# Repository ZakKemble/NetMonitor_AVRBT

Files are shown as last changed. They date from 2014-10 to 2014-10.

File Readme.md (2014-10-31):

Bluetooth Net Monitor
=====================

http://blog.zakkemble.co.uk/bluetooth-net-monitor-v2/

The firmware .hex files (bootloader & monitor) are compiled for ATmega328P

Fuses for ATmega328/328P  
External full swing crystal 16K CK/14CK + 65ms startup  
Serial program (SPI) enabled  
Brown-out at 2.7V  
Bootloader enabled, 2048 words  
High:		0xD8 (or 0xDF for no bootloader)  
Low:		0xF7  
Extended:	0xFD

--------

`./modem/adsl_btnetmon`  
This is the CGI script which runs on the modem to get ADSL stats (Only tested on Netgear DG834G v3 running OpenWRT)

`./router/btnetmon`  
This is the main program which runs on the router, the binary was compiled on Debain 7.7 x64 so it may or may not work without having to recompile (differently named libs, etc). More info in `./router/Readme.md`

`./utils/lcdBitmapConverter.exe`  
Utility to convert red channel of images (in `./imgs/`) to pixel intensity byte array

`./driver/` contains parts of libusb-win32 available at http://sourceforge.net/apps/trac/libusb-win32/wiki  
`./firmware/` contains the V-USB library available at http://www.obdev.at/products/vusb/index.html  
`./firmware/USBaspLoader/` contains the USBaspLoader bootloader available at https://github.com/baerwolf/USBaspLoader  
Font used is MicroExtendFLF (bold italics) available at http://www.fontspace.com/casady-and-greene/microextendflf  
Third party contents are copyrighted by their respective authors.  
My productions are published under GNU GPL v3 (see License.txt).

--------

Zak Kemble

contact@zakkemble.co.uk

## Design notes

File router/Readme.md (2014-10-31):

Quick setup guide for the router
================================

Plug a USB bluetooth adapter into the router  
Plug the net monitor into anywhere

Compiling:
```
apt-get install gcc liboping-dev libcurl4-gnutls-dev libbluetooth-dev bluez
chmod +x make.sh
./make.sh
```

Search for the net monitor:
```
hcitool scan
```

One of the lines should be the net monitor, copy the hex address string for it.

Set up config:  
Open ./btnetmon.conf  
Set btaddr to the hex address for the net monitor  
`btaddr=AA:BB:CC.....`  
Make sure all the other settings are OK  

Paring:  
`bluetooth-agent 1234 &`  
1234 is the PIN for the net monitor.  

Run main program:  
`./btnetmon -d`

If it successfully connects then CTRL + C.

`pkill bluetooth-agent`  
You don't need to do the bluetooth-agent things again, it's only needed for the first connection.

`./btnetmon`  
Program should now be running in the background.

If for some crazy reason it stops being able to connect to the net monitor run:  
`rm -r /var/lib/bluetooth/(btaddr)/`  
That will clear all saved settings for the bluetooth device with that address, then do the bluetooth-agent stuff again.

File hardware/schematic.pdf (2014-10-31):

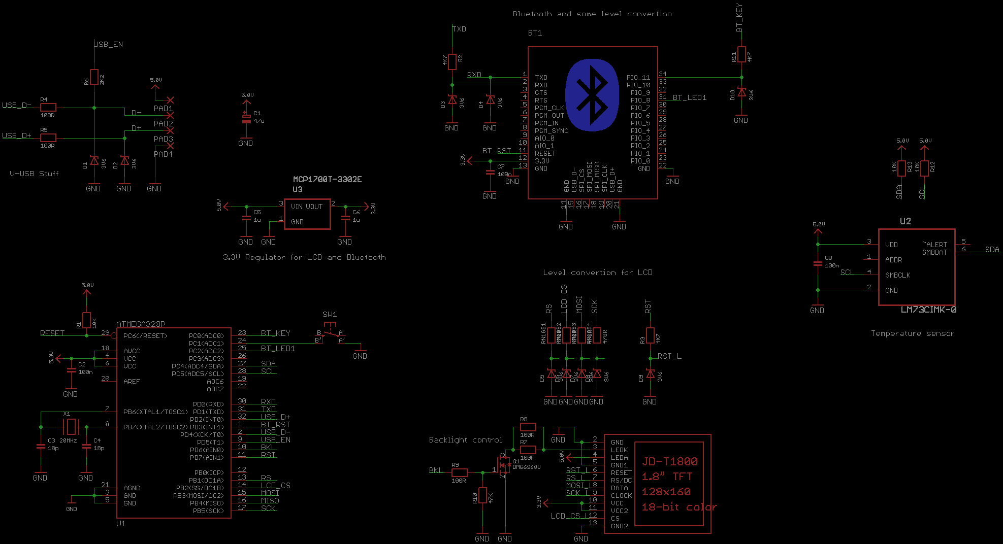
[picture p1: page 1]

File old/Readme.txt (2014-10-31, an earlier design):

THIS IS OLD STUFF FOR BLUETOOTH NET MONITOR V1

Bluetooth Net Monitor
http://blog.zakkemble.co.uk/bluetooth-net-monitor/

The .hex file in ./firmware/hex/ is compiled for ATmega328P
Fuse settings are in ./firmware/src/config.h

./scripts/modem/adsl_btnetmon
This is the CGI script which runs on the modem to get ADSL stats

./scripts/router/btnetmon.sh
This is the main shell script which runs on the router

./utils/lcdBitmapConverter.exe
Utility to convert red channel of images (in ./imgs/) to pixel intensity byte array

The ./driver/ directory contain parts of libusb-win32 available at http://sourceforge.net/apps/trac/libusb-win32/wiki
The ./firmware/src/ directory and subdirectories contains the V-USB library available at http://www.obdev.at/products/vusb/index.html
Third party contents are copyrighted by their respective authors.
My productions are published under GNU GPL v3 (see License.txt).

--------

Zak Kemble
me@zakkemble.co.uk

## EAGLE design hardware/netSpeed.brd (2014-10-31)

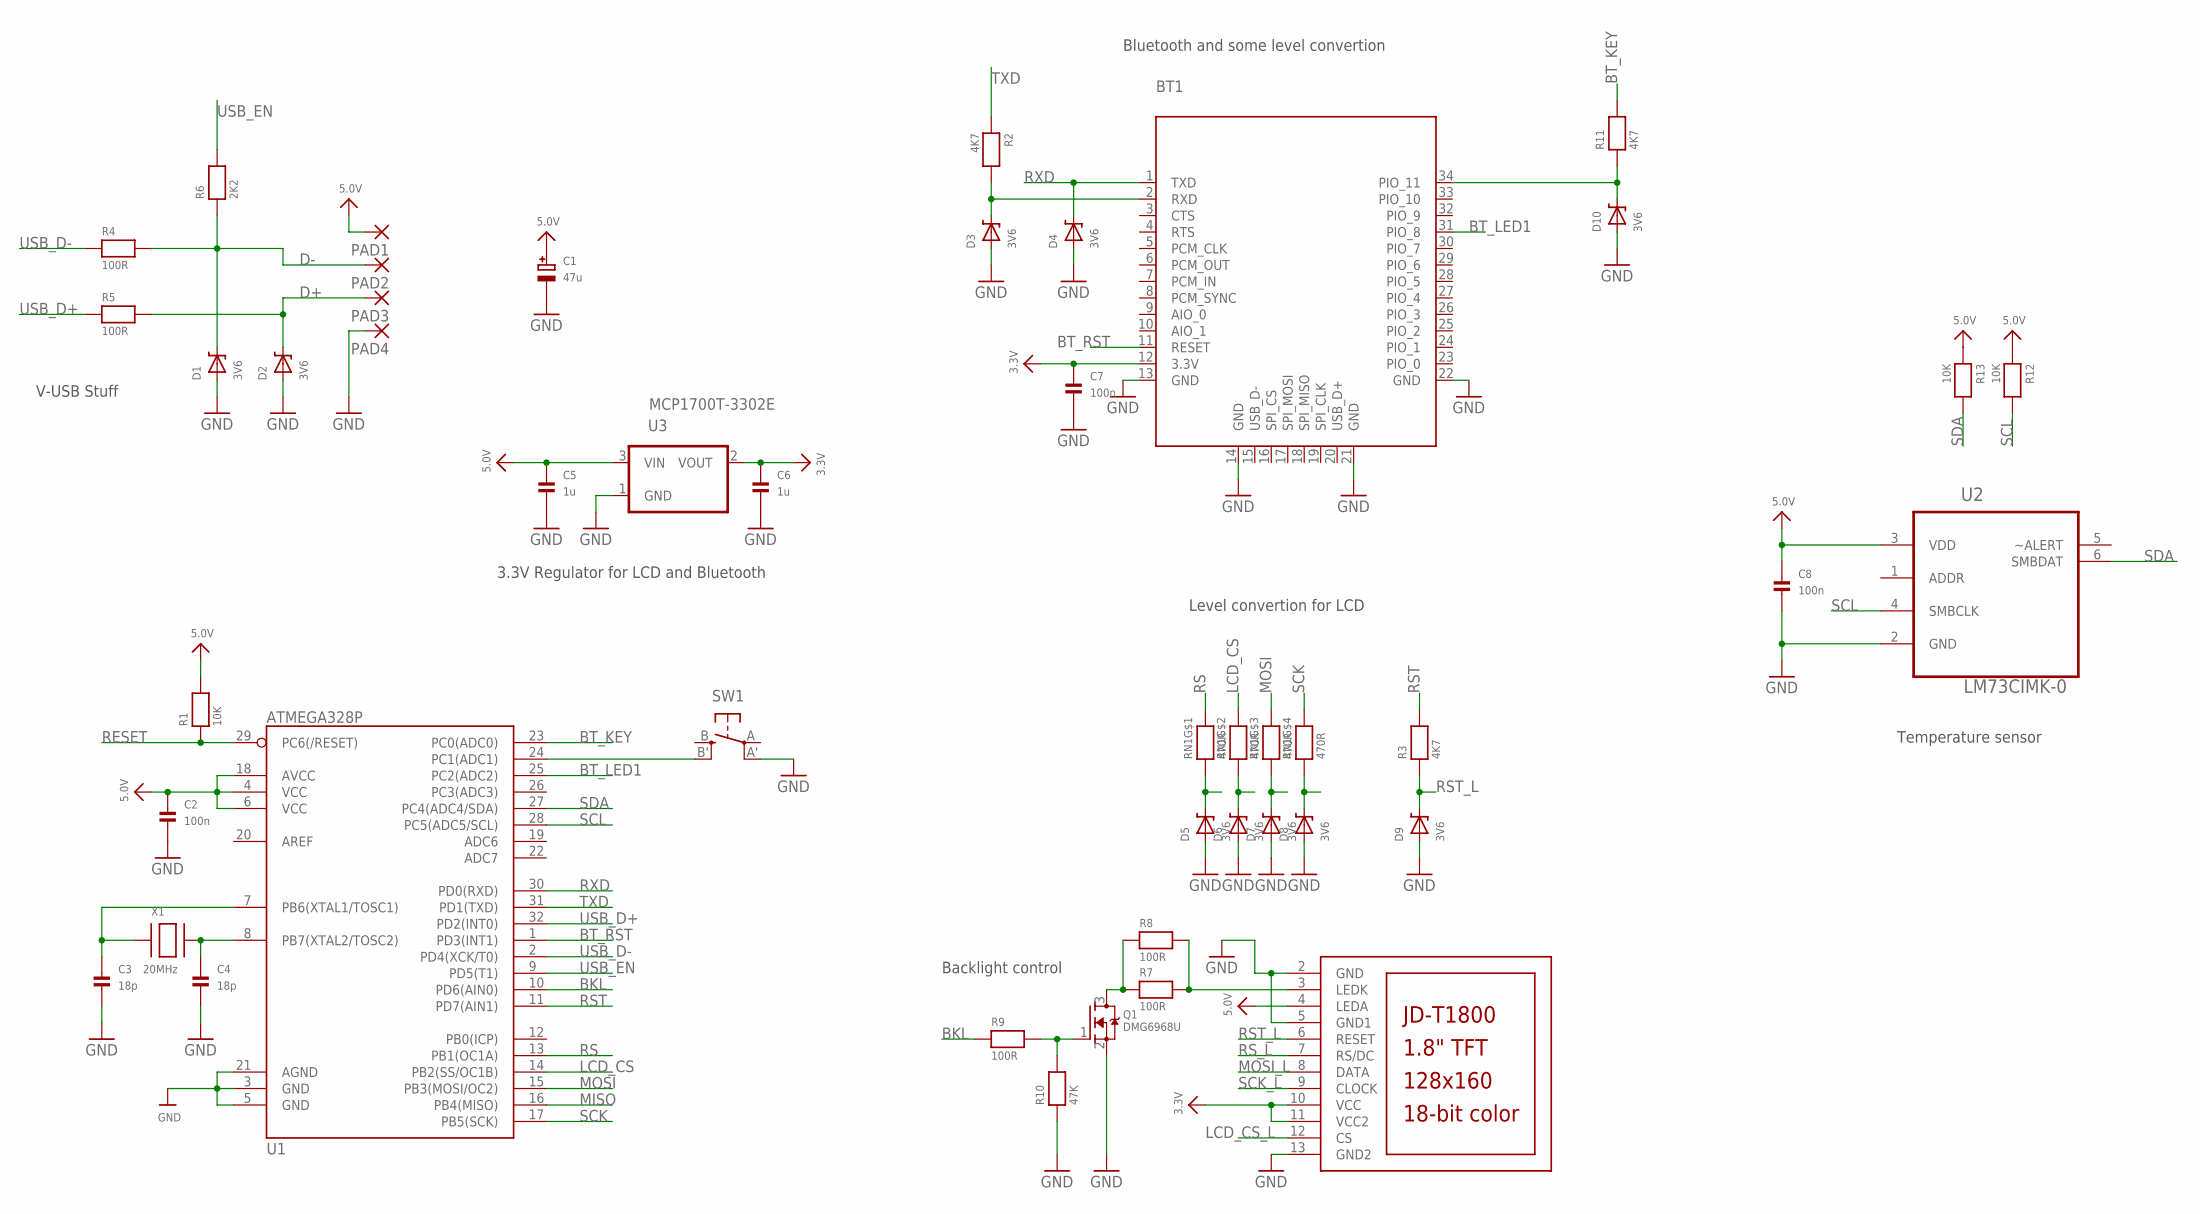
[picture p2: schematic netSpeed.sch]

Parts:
BT1: BLUETOOTH_MODULE
C1: 47u; PANASONIC_C
C2, C7, C8: 100n; 0805
C3, C4: 18p; 0805
C5, C6: 1u; 0805
D1, D2, D3, D4, D5, D6, D7, D8, D9, D10: 3V6; SOD-323
LCD1: JD-T1800
PAD1, PAD2, PAD3, PAD4: SMD2; SMD1,27-2,54
Q1: DMG6968U; SOT23-WIDE
R1, R12, R13: 10K; 0805
R2, R3, R11: 4K7; 0805
R4, R5, R7, R8, R9: 100R; 0805
R6: 2K2; 0805
R10: 47K; 0805
RN1: 470R; RESPACK_4X0603
SW1: SPST_TACT; TACT_SMD
U1: ATMEGA328P; TQFP32-08
U2: LM73CIMK-0; SOT95P285X100-6N
U3: MCP1700T-3302E; SOT-23
X1: 20MHz; NX5032

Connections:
3.3V: BT1.12 (3.3V), C6.1, C7.1, LCD1.10 (VCC), LCD1.11 (VCC2), U3.2 (VOUT)
5.0V: C1.+, C2.1, C5.1, C8.1, LCD1.4 (LEDA), PAD1.1, R1.2, R12.1, R13.1, U1.4 (VCC), U1.6 (VCC), U1.18 (AVCC), U2.3 (VDD), U3.3 (VIN)
BKL: R9.1, U1.10 (PD6(AIN0))
BT_KEY: R11.2, U1.23 (PC0(ADC0))
BT_KEY_L: BT1.34 (PIO_11), D10.C, R11.1
BT_LED1: BT1.31 (PIO_8), U1.25 (PC2(ADC2))
BT_RST: BT1.11 (RESET), U1.1 (PD3(INT1))
D+: D2.C, PAD3.1, R5.2
D-: D1.C, PAD2.1, R4.2, R6.1
GND: BT1.13 (GND), BT1.14 (GND), BT1.21 (GND), BT1.22 (GND), C1.-, C2.2, C3.2, C4.2, C5.2, C6.2, C7.2, C8.2, D1.A, D2.A, D3.A, D4.A, D5.A, D6.A, D7.A, D8.A, D9.A, D10.A, LCD1.2 (GND), LCD1.5 (GND1), LCD1.13 (GND2), PAD4.1, Q1.2 (S), R10.1, SW1.A' (P1), U1.3 (GND), U1.5 (GND), U1.21 (AGND), U2.2 (GND), U3.1 (GND)
LCD_CS: RN1.7 (2), U1.14 (PB2(SS/OC1B))
LCD_CS_L: D6.C, LCD1.12 (CS), RN1.2 (1)
MISO: U1.16 (PB4(MISO))
MOSI: RN1.6 (2), U1.15 (PB3(MOSI/OC2))
MOSI_L: D7.C, LCD1.8 (DATA), RN1.3 (1)
unnamed: SW1.B' (S1), U1.24 (PC1(ADC1))
unnamed: C3.1, U1.7 (PB6(XTAL1/TOSC1)), X1.P$1
unnamed: C4.1, U1.8 (PB7(XTAL2/TOSC2)), X1.P$2
unnamed: Q1.1 (G), R9.2, R10.2
unnamed: Q1.3 (D), R7.1, R8.1
unnamed: LCD1.3 (LEDK), R7.2, R8.2
RESET: R1.1, U1.29 (PC6(/RESET))
RS: RN1.8 (2), U1.13 (PB1(OC1A))
RST: R3.2, U1.11 (PD7(AIN1))
RST_L: D9.C, LCD1.6 (RESET), R3.1
RS_L: D5.C, LCD1.7 (RS/DC), RN1.1
RXD: BT1.1 (TXD), D4.C, U1.30 (PD0(RXD))
SCK: RN1.5 (2), U1.17 (PB5(SCK))
SCK_L: D8.C, LCD1.9 (CLOCK), RN1.4 (1)
SCL: R12.2, U1.28 (PC5(ADC5/SCL)), U2.4 (SMBCLK)
SDA: R13.2, U1.27 (PC4(ADC4/SDA)), U2.6 (SMBDAT)
TXD: R2.1, U1.31 (PD1(TXD))
TXD_L: BT1.2 (RXD), D3.C, R2.2
USB_D+: R5.1, U1.32 (PD2(INT0))
USB_D-: R4.1, U1.2 (PD4(XCK/T0))
USB_EN: R6.2, U1.9 (PD5(T1))

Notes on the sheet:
Level convertion for LCD
Temperature sensor
Bluetooth and some level convertion
V-USB Stuff
3.3V Regulator for LCD and Bluetooth
Backlight control

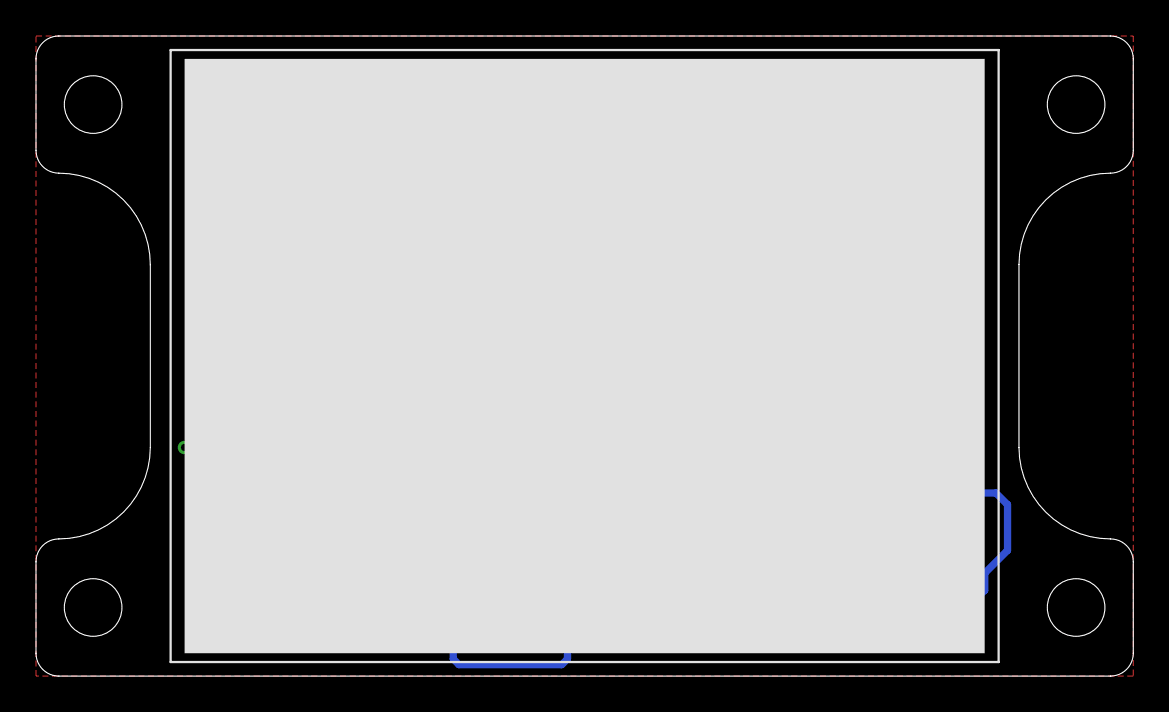
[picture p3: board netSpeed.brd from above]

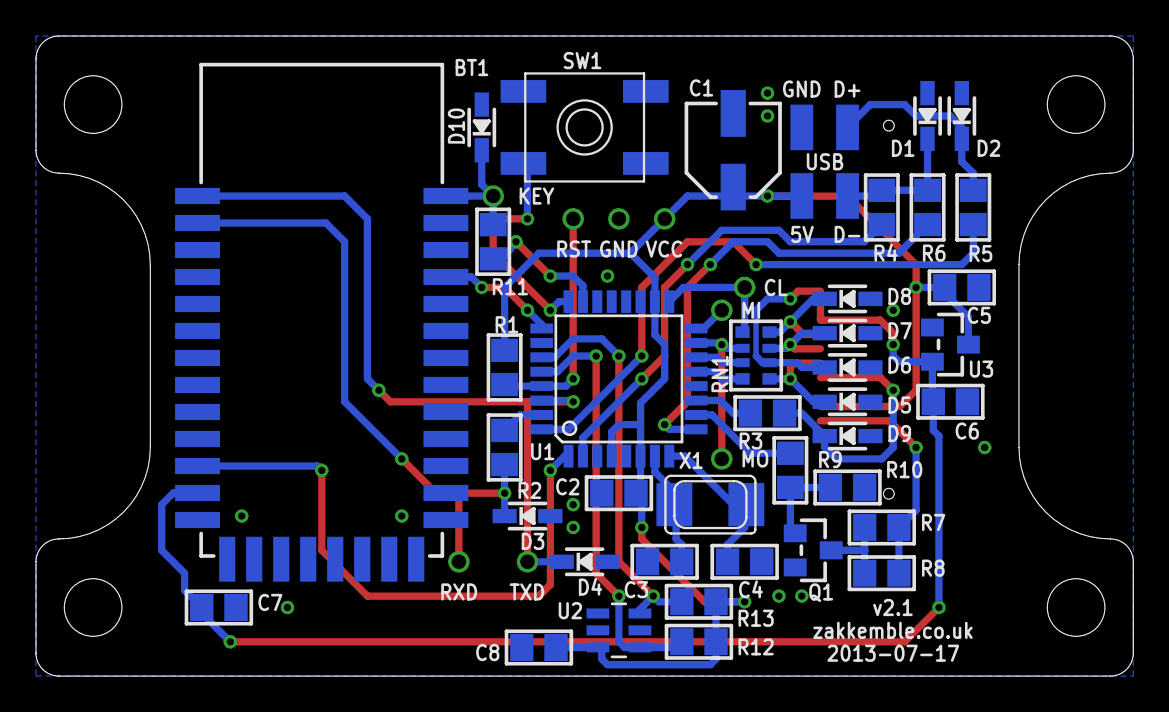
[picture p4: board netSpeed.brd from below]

Board: 2 copper layers, 61.0 x 35.6 mm, 44 parts (43 on the bottom side), 35 nets.

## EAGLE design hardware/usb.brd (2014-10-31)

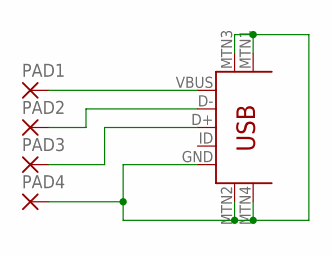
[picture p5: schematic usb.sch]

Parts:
PAD1, PAD2, PAD3, PAD4: SMD2; SMD1,27-2,54
USB1: USB-MINIB-5PIN; USB-MINIB

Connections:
GND: PAD4.1, USB1.GND, USB1.MTN1 (MTN2), USB1.MTN2 (MTN3), USB1.MTN3 (MTN1), USB1.MTN4
unnamed: PAD1.1, USB1.VBUS
unnamed: PAD2.1, USB1.D-
unnamed: PAD3.1, USB1.D+

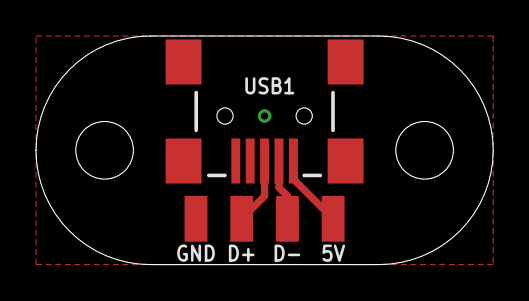
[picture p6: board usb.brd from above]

Board: 2 copper layers, 25.4 x 12.7 mm, 5 parts (0 on the bottom side), 4 nets.

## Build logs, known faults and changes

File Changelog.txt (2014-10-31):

2014-10-31:
	Router program:
	- Support for USB bluetooth adapters (rfcomm)
	- Support for non-point-to-point interfaces
	- Can manually set sync rates

	Net Monitor:
	- Now shows speeds in MBps with 1 decimal place (0.0 - 99.9MBps)

2013-08-17:
	- Version 2!
	- New PCB design
	- Revamped micorcontroller code, reduced RAM usage, improved performance
	- New router program, now written in C, much more efficient than the old shell script
	- New host program, written in C# .NET and uses LibUsbDotNet. Still in early development, but allows image uploading, drawing and controlling display brightness
	- Added a bootloader (USBaspLoader) for easy firmware updating over USB

2013-01-09:
	- Initial release

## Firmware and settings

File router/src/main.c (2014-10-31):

/*
 * Project: Bluetooth Net Monitor
 * Author: Zak Kemble, contact@zakkemble.co.uk
 * Copyright: (C) 2013 by Zak Kemble
 * License: GNU GPL v3 (see License.txt)
 * Web: http://blog.zakkemble.co.uk/bluetooth-net-monitor-v2/
 */

// TODO:
// Keep byte count files always open?
// Instead of ping and main threads having their own sleep(), have a single sleep() which notifies other threads?
// If no responce from modem then sync speeds should be set to 0
// PIN and BT adpater settings
// Support routers that need to go through multiple login pages and cookies and stuff
// http://icanhazip.com/

// BUGS:
// Sometimes program crashes when interface comes up
// Single instance stuff doesn't work yet
// Ping doesn't work if non-root, needs CAP_NET_RAW capability since liboping uses raw sockets
// If interface is unavailable ping is 999 (good), but lost packet count does not go up (bad)


// v1.1 changes
// Fixed cURL stuff stops working with 'Failure when receiving data from the peer'
// Support for BT USB adapters
// Renamed adsl.c to modem.c
// Can now manually set sync rate
// Support for speeds over 999 KBps / syncs over 9999 Kbps (now goes to 99.9MBps / 99999 Kbps)
// Support non-Point-to-Point interfaces



#include "common.h"

#define SENDBUFFER_SIZE	30

typedef struct{
	byte data[SENDBUFFER_SIZE];
	byte* ptr;
}s_sendBuffer;

static void incArgIdx(int*, int);
static bool alreadyRunning(void);
static void update(void);
static void bufferWriter(s_sendBuffer*, void*, byte);
static ulong readFileAsNum(const char*);
//static int writeToBuffer(char**, const char*, ...);
static void print_ip(uint32_t);

static bool daemonize;

// Byte count file locations
static char* byteCountFileRx;
static char* byteCountFileTx;

typedef void (*adapterInit_f)(void);
typedef void (*adapterEnd_f)(void);
typedef void (*adapterSend_f)(void*, size_t);

static adapterInit_f adapterInitFunc;
static adapterEnd_f adapterEndFunc;
static adapterSend_f adapterSendFunc;

int main(int argc, char **argv)
{
	puts("Bluetooth Net Monitor v1.1");
	puts("zakkemble.co.uk");

//	syslog(LOG_DAEMON | LOG_INFO, "Bluetooth Net Monitor v1.0 started");

	daemonize = true;
	char* configFile = NULL;

	// Check args
	for(int argIdx = 1;argIdx<argc;argIdx++)
	{
		if(strcmp(argv[argIdx], "-h") == 0 || strcmp(argv[argIdx], "--help") == 0)
		{
			printf("Usage: %s [--help|-h] [-c <file>] [-d]", argv[0]);
			puts("");
			puts(" --help|-h : Help (This)");
			puts(" -c <file> : Config file location (Default looks for btnetmon.conf in working directory)");
			puts("        -d : Don't daemonize (Debugging)");
			exit(EXIT_SUCCESS);
		}
		else if(strcmp(argv[argIdx], "-c") == 0)
		{
			incArgIdx(&argIdx, argc);
			asprintf(&configFile, "%s", argv[argIdx]);
		}
		else if(strcmp(argv[argIdx], "-d") == 0)
			daemonize = false;
	}

	// Default config file
	if(!configFile)
		asprintf(&configFile, "btnetmon.conf");

	// Load config
	config_init(configFile);

	// No longer needed
	free(configFile);

	// Make sure only 1 instance is running
	if(alreadyRunning())
	{
		fputs("Error: Another instance is already running", stderr);
		exit(EXIT_FAILURE);
	}

	// Run in background
	if(daemonize && daemon(0, 0) < 0)
		error(EXIT_FAILURE, errno, "Failed to daemonize");

	// Bluetooth adapter type
	char* btType = NULL;
	config_val("bttype", &btType);
	
	if(strcmp(btType, "serial") == 0)
	{
		adapterInitFunc = serial_init;
		adapterEndFunc = serial_end;
		adapterSendFunc = serial_send;
	}
	else if(strcmp(btType, "usb") == 0)
	{
		adapterInitFunc = rfcomm_init;
		adapterEndFunc = rfcomm_end;
		adapterSendFunc = rfcomm_send;
	}
	else
	{
		fprintf(stderr, "Error: Unknown btType option: %s\n", btType);
		exit(EXIT_FAILURE);
	}

	free(btType);

	// Init
	curl_global_init(CURL_GLOBAL_ALL);
	adapterInitFunc();
	email_init();
	modem_init();
	iface_init();
	ping_init();

	// Get interface byte count file locations
	char* interface = NULL;
	config_val("interface", &interface);

	asprintf(&byteCountFileRx, "/sys/class/net/%s/statistics/rx_bytes", interface);
	asprintf(&byteCountFileTx, "/sys/class/net/%s/statistics/tx_bytes", interface);

	free(interface);

	// Free config resources
	config_end();

	struct timespec sleepTime;
	sleepTime.tv_sec = 1;
	sleepTime.tv_nsec = 0;

	//for(int i=0;i<5;i++)
	while(1)
	{
		nanosleep(&sleepTime, NULL);

		//struct timespec startTime;
		//clock_gettime(CLOCK_THREAD_CPUTIME_ID, &startTime);

		update();

		//struct timespec endTime;
		//clock_gettime(CLOCK_THREAD_CPUTIME_ID, &endTime);

		//printf("Total time: %ldns\n", endTime.tv_nsec - startTime.tv_nsec);
	}

	// Free everything, although program never ends unless its manually killed
	free(byteCountFileRx);
	free(byteCountFileTx);
	adapterEndFunc();
	iface_end();
	email_end();
	modem_end();
	ping_end();
	curl_global_cleanup();

	return EXIT_SUCCESS;
}

static void incArgIdx(int* argIdx, int argc)
{
	if(++*argIdx >= argc)
	{
		puts("Error: Bad/missing arguments");
		exit(EXIT_FAILURE);
	}
}

// This isn't working quite right yet, file lock stuff doesn't lock...
static bool alreadyRunning()
{
	char* pid = NULL;
	config_val("pid", &pid);

	// If PID file setting is empty then don't do any PID stuff
	if(strlen(pid) < 1)
		return false;

	// Create/open file
	int pid_file = open(pid, O_CREAT | O_WRONLY | O_TRUNC, 0644);

	if(pid_file < 0)
	{
		perror("Unable to create PID file");
		exit(EXIT_FAILURE);
	}

	if(pid)
		free(pid);

	// Get PID
	char* buff = NULL;
	int len = asprintf(&buff, "%d", getpid());

	// Write PID
	int res = write(pid_file, buff, len);
	UNUSED(res);

	if(buff)
		free(buff);

	// Try to lock file
	struct flock lock;
	lock.l_type		= F_WRLCK;
	lock.l_whence	= SEEK_SET;
	lock.l_start	= 0;
	lock.l_len		= 0;
	lock.l_pid		= getpid();
	int rc = fcntl(pid_file, F_SETLK, &lock);

	return (rc != 0);
}

// Main update function
static void update()
{
	static ulong lastBytesDown;
	static ulong lastBytesUp;

	// Start update threads and stuff
	email_update();
	modem_update();
	iface_update();

	// Get what IP to ping
	ping_setHost(iface_gateway());

	// Get current byte count
	ulong bytesDown = readFileAsNum(byteCountFileRx);
	ulong bytesUp = readFileAsNum(byteCountFileTx);

	// Work out rates
	s_netUpDown rate;
	rate.down = (uint32_t)((bytesDown - lastBytesDown) / 1024);
	rate.up = (uint32_t)((bytesUp - lastBytesUp) / 1024);

	// Save byte counts for next time
	lastBytesDown = bytesDown;
	lastBytesUp = bytesUp;

	// IP
	uint32_t ip = iface_ip();

	// Time
	time_t rawTime;
	struct tm* timeInfo;
	time(&rawTime);
	timeInfo = localtime(&rawTime);

	// ADSL sync rates
	s_netUpDown adsl = modem_get();

	// Email
	bool hasEmail = email_get();

	// Ping
	uint16_t ping = ping_get();

	// Ping loss
	byte loss = ping_loss();

	if(!daemonize)
	{
		// Show info
		printf("Sync ---- Down: %u -- Up: %u\n", adsl.down, adsl.up);
		printf("Rates ---- Down: %u -- Up: %u\n", rate.down, rate.up);
		print_ip(ip);
		printf("Gateway: %s\n", iface_gateway());
		printf("Ping: %hu | Loss: %hhu\n", ping, loss);
		hasEmail ? puts("Email!") : puts("No email");
		printf("Time: %s\n", asctime(timeInfo));
	}

	// Write data to buffer for sending to the net monitor
	s_sendBuffer buffer;
	memset(&buffer.data, 0, sizeof(buffer.data));
	buffer.ptr = buffer.data;

	bufferWriter(&buffer, &adsl.down, 4);
	bufferWriter(&buffer, &adsl.up, 4);
	bufferWriter(&buffer, &rate.down, 4);
	bufferWriter(&buffer, &rate.up, 4);
	bufferWriter(&buffer, &ping, 2);
	bufferWriter(&buffer, &loss, 1);
	bufferWriter(&buffer, &ip, 4);
	bufferWriter(&buffer, &hasEmail, 1);
	bufferWriter(&buffer, &timeInfo->tm_hour, 1);
	bufferWriter(&buffer, &timeInfo->tm_min, 1);
	bufferWriter(&buffer, &timeInfo->tm_sec, 1);
	bufferWriter(&buffer, &timeInfo->tm_mday, 1);
	bufferWriter(&buffer, &timeInfo->tm_mon, 1);
	bufferWriter(&buffer, &timeInfo->tm_year, 1);

	if(!daemonize)
	{
		// Show contents
		for(size_t i=0;i<sizeof(buffer.data);i++)
			printf("%02x ", buffer.data[i]);
		puts("");

		puts("----");
	}

	// Send to the net monitor
	adapterSendFunc(buffer.data, sizeof(buffer.data));
}

static void bufferWriter(s_sendBuffer* buffer, void* src, byte len)
{
	memcpy(buffer->ptr, src, len);
	buffer->ptr += len;
}

// Read a file and convert its contents to ulong
static ulong readFileAsNum(const char* file)
{
	// Open file
	FILE* fp = fopen(file, "r");
	if(!fp)
	{
		fprintf(stderr, "Coult not open file %s", file);
		perror(" ");
		return 0;
	}

	// Make buffer
	char buffer[21];
	memset(buffer, 0, sizeof(buffer));

	// Read contents
	int res = fread(buffer, sizeof(char), sizeof(buffer) - 1, fp);
	UNUSED(res);

	// Convert to ulong
	ulong num = strtoul(buffer, NULL, 10);

	// Close file
	fclose(fp);

	return num;
}

/*
// http://stackoverflow.com/questions/3774417/sprintf-with-automatic-memory-allocation
// using asprintf() instead
static int writeToBuffer(char** buff, const char* fmt, ...)
{
	va_list args1;
	va_list args2; // Using the same va_list in more than 1 place messes things up?
	va_start(args1, fmt);
	va_start(args2, fmt);

	// Get required buffer size (+ 1 for null terminator)
	int len = vsnprintf(NULL, 0, fmt, args1) + 1;

	if(*buff) // realloc instead?
		free(*buff);
	*buff = malloc(len);

	// Write formatted string
	vsnprintf(*buff, len, fmt, args2);

	va_end(args1);
	va_end(args2);

//	printf("%d %s\n", len, *buff);
	return len;
}
*/

// Print Int32 IP
static void print_ip(uint32_t ip)
{
	byte octects[4];
	octects[0] = ip & 0xFF;
	octects[1] = (ip >> 8) & 0xFF;
	octects[2] = (ip >> 16) & 0xFF;
	octects[3] = (ip >> 24) & 0xFF;	
	printf("IP: %hhu.%hhu.%hhu.%hhu\n", octects[0], octects[1], octects[2], octects[3]);        
}

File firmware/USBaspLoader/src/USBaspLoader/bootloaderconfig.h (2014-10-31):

/* Name: bootloaderconfig.h
 * Project: USBaspLoader
 * Author: Christian Starkjohann
 * Author: Stephan Baerwolf
 * Creation Date: 2007-12-08
 * Modification Date: 2013-03-31
 * Tabsize: 4
 * Copyright: (c) 2007 by OBJECTIVE DEVELOPMENT Software GmbH
 * License: GNU GPL v2 (see License.txt)
 */

#ifndef __bootloaderconfig_h_included__
#define __bootloaderconfig_h_included__
#include <avr/io.h>

/*
General Description:
This file (together with some settings in Makefile) configures the boot loader
according to the hardware.

This file contains (besides the hardware configuration normally found in
usbconfig.h) two functions or macros: bootLoaderInit() and
bootLoaderCondition(). Whether you implement them as macros or as static
inline functions is up to you, decide based on code size and convenience.

bootLoaderInit() is called as one of the first actions after reset. It should
be a minimum initialization of the hardware so that the boot loader condition
can be read. This will usually consist of activating a pull-up resistor for an
external jumper which selects boot loader mode.

bootLoaderCondition() is called immediately after initialization and in each
main loop iteration. If it returns TRUE, the boot loader will be active. If it
returns FALSE, the boot loader jumps to address 0 (the loaded application)
immediately.

For compatibility with Thomas Fischl's avrusbboot, we also support the macro
names BOOTLOADER_INIT and BOOTLOADER_CONDITION for this functionality. If
these macros are defined, the boot loader usees them.
*/

/* ---------------------------- Macro Magic ---------------------------- */
#define		PIN_CONCAT(a,b)			a ## b
#define		PIN_CONCAT3(a,b,c)		a ## b ## c

#define		PIN_PORT(a)			PIN_CONCAT(PORT, a)
#define		PIN_PIN(a)			PIN_CONCAT(PIN, a)
#define		PIN_DDR(a)			PIN_CONCAT(DDR, a)

#define		PIN(a, b)			PIN_CONCAT3(P, a, b)

/* ---------------------------- Hardware Config ---------------------------- */

#ifndef USB_CFG_IOPORTNAME
  #define USB_CFG_IOPORTNAME      D
#endif
/* This is the port where the USB bus is connected. When you configure it to
 * "B", the registers PORTB, PINB and DDRB will be used.
 */
#ifndef USB_CFG_INTPORT_BIT
  #if (defined(__AVR_ATmega640__) || defined(__AVR_ATmega1280__) || defined(__AVR_ATmega1281__) || defined(__AVR_ATmega2560__) || defined(__AVR_ATmega2561__))
    #define USB_CFG_INTPORT_BIT 0
  #else
    #define USB_CFG_INTPORT_BIT 2
  #endif
#endif
/* Not all devices have their INT0 on PD2.
 * Since "INT0" and "USB_CFG_DPLUS_BIT" should get the same signals,
 * map them to be ideally the same:
 * So abstract "USB_CFG_DPLUS_BIT" to this one here.
 */

#ifndef USB_CFG_DMINUS_BIT
  /* This is Revision 3 and later (where PD6 and PD7 were swapped */
  #define USB_CFG_DMINUS_BIT      4    /* Rev.2 and previous was 6 */
#endif
/* This is the bit number in USB_CFG_IOPORT where the USB D- line is connected.
 * This may be any bit in the port.
 */
#ifndef USB_CFG_DPLUS_BIT
  #define USB_CFG_DPLUS_BIT       USB_CFG_INTPORT_BIT
#endif
/* This is the bit number in USB_CFG_IOPORT where the USB D+ line is connected.
 * This may be any bit in the port. Please note that D+ must also be connected
 * to interrupt pin INT0!
 */
#ifndef JUMPER_PORT
  #define JUMPER_PORT		C
#endif
/* 
 * jumper is connected to this port
 */
#ifndef JUMPER_BIT
  /* This is Revision 3 and later (where PD6 and PD7 were swapped */
  #define JUMPER_BIT           1       /* Rev.2 and previous was 7 */
#endif
/* 
 * jumper is connected to this bit in port "JUMPER_PORT", active low
 */

#define USB_CFG_CLOCK_KHZ       (F_CPU/1000)
/* Clock rate of the AVR in MHz. Legal values are 12000, 16000 or 16500.
 * The 16.5 MHz version of the code requires no crystal, it tolerates +/- 1%
 * deviation from the nominal frequency. All other rates require a precision
 * of 2000 ppm and thus a crystal!
 * Default if not specified: 12 MHz
 */

/* ----------------------- Optional Hardware Config ------------------------ */

#define USB_CFG_PULLUP_IOPORTNAME   D
/* If you connect the 1.5k pullup resistor from D- to a port pin instead of
 * V+, you can connect and disconnect the device from firmware by calling
 * the macros usbDeviceConnect() and usbDeviceDisconnect() (see usbdrv.h).
 * This constant defines the port on which the pullup resistor is connected.
 */
#define USB_CFG_PULLUP_BIT          5
/* This constant defines the bit number in USB_CFG_PULLUP_IOPORT (defined
 * above) where the 1.5k pullup resistor is connected. See description
 * above for details.
 */

/* ------------------------------------------------------------------------- */
/* ---------------------- feature / code size options ---------------------- */
/* ------------------------------------------------------------------------- */
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

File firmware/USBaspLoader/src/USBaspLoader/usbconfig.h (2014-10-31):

/* Name: usbconfig.h
 * Project: V-USB, virtual USB port for Atmel's(r) AVR(r) microcontrollers
 * Author: Christian Starkjohann
 * Creation Date: 2005-04-01
 * Tabsize: 4
 * Copyright: (c) 2005 by OBJECTIVE DEVELOPMENT Software GmbH
 * License: GNU GPL v2 (see License.txt), GNU GPL v3 or proprietary (CommercialLicense.txt)
 */

#ifndef __usbconfig_h_included__
#define __usbconfig_h_included__

/* YOU SHOULD NOT NEED TO MODIFY THIS FILE! All configurations are supposed
 * to go into bootloaderconfig.h!
 */

/* ---------------------------- Hardware Config ---------------------------- */

/* All the port and pin assignments, as well as the clock speed and CRC
   setting are now in bootloaderconfig.h: */

#include "bootloaderconfig.h"

/* --------------------------- Functional Range ---------------------------- */

#define USB_CFG_HAVE_INTRIN_ENDPOINT    0
/* Define this to 1 if you want to compile a version with two endpoints: The
 * default control endpoint 0 and an interrupt-in endpoint (any other endpoint
 * number).
 */
#define USB_CFG_HAVE_INTRIN_ENDPOINT3   0
/* Define this to 1 if you want to compile a version with three endpoints: The
 * default control endpoint 0, an interrupt-in endpoint 3 (or the number
 * configured below) and a catch-all default interrupt-in endpoint as above.
 * You must also define USB_CFG_HAVE_INTRIN_ENDPOINT to 1 for this feature.
 */
#define USB_CFG_EP3_NUMBER              3
/* If the so-called endpoint 3 is used, it can now be configured to any other
 * endpoint number (except 0) with this macro. Default if undefined is 3.
 */
/* #define USB_INITIAL_DATATOKEN           USBPID_DATA1 */
/* The above macro defines the startup condition for data toggling on the
 * interrupt/bulk endpoints 1 and 3. Defaults to USBPID_DATA1.
 * Since the token is toggled BEFORE sending any data, the first packet is
 * sent with the oposite value of this configuration!
 */
#define USB_CFG_IMPLEMENT_HALT          0
/* Define this to 1 if you also want to implement the ENDPOINT_HALT feature
 * for endpoint 1 (interrupt endpoint). Although you may not need this feature,
 * it is required by the standard. We have made it a config option because it
 * bloats the code considerably.
 */
#define USB_CFG_SUPPRESS_INTR_CODE      0
/* Define this to 1 if you want to declare interrupt-in endpoints, but don't
 * want to send any data over them. If this macro is defined to 1, functions
 * usbSetInterrupt() and usbSetInterrupt3() are omitted. This is useful if
 * you need the interrupt-in endpoints in order to comply to an interface
 * (e.g. HID), but never want to send any data. This option saves a couple
 * of bytes in flash memory and the transmit buffers in RAM.
 */
#define USB_CFG_INTR_POLL_INTERVAL      10
/* If you compile a version with endpoint 1 (interrupt-in), this is the poll
 * interval. The value is in milliseconds and must not be less than 10 ms for
 * low speed devices.
 */
#ifndef USB_CFG_IS_SELF_POWERED // allow bootloaderconfig.h to override
#define USB_CFG_IS_SELF_POWERED         0
#endif
/* Define this to 1 if the device has its own power supply. Set it to 0 if the
 * device is powered from the USB bus.
 */
#ifndef USB_CFG_MAX_BUS_POWER   // allow bootloaderconfig.h to override
#define USB_CFG_MAX_BUS_POWER           200
#endif
/* Set this variable to the maximum USB bus power consumption of your device.
 * The value is in milliamperes. [It will be divided by two since USB
 * communicates power requirements in units of 2 mA.]
 */
#define USB_CFG_IMPLEMENT_FN_WRITE      1
/* Set this to 1 if you want usbFunctionWrite() to be called for control-out
 * transfers. Set it to 0 if you don't need it and want to save a couple of
 * bytes.
 */
#define USB_CFG_IMPLEMENT_FN_READ       1
/* Set this to 1 if you need to send control replies which are generated
 * "on the fly" when usbFunctionRead() is called. If you only want to send
 * data from a static buffer, set it to 0 and return the data from
 * usbFunctionSetup(). This saves a couple of bytes.
 */
#define USB_CFG_IMPLEMENT_FN_WRITEOUT   0
/* Define this to 1 if you want to use interrupt-out (or bulk out) endpoints.
 * You must implement the function usbFunctionWriteOut() which receives all
 * interrupt/bulk data sent to any endpoint other than 0. The endpoint number
 * can be found in 'usbRxToken'.
 */
#define USB_CFG_HAVE_FLOWCONTROL        0
/* Define this to 1 if you want flowcontrol over USB data. See the definition
 * of the macros usbDisableAllRequests() and usbEnableAllRequests() in
 * usbdrv.h.
 */
#if defined(BOOTLOADER_ADDRESS)
#	define USB_CFG_DRIVER_FLASH_PAGE       (BOOTLOADER_ADDRESS >> 16)
#else
#	define USB_CFG_DRIVER_FLASH_PAGE       0
#endif
/* If the device has more than 64 kBytes of flash, define this to the 64 k page
 * where the driver's constants (descriptors) are located. Or in other words:
 * Define this to 1 for boot loaders on the ATMega128.
 */
#define USB_CFG_LONG_TRANSFERS          0
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

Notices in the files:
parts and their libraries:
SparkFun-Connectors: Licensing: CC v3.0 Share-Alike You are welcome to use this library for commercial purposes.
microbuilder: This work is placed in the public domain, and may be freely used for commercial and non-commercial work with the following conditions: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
